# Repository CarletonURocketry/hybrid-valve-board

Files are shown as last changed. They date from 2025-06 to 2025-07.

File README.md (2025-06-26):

# Hybrid Valve Board

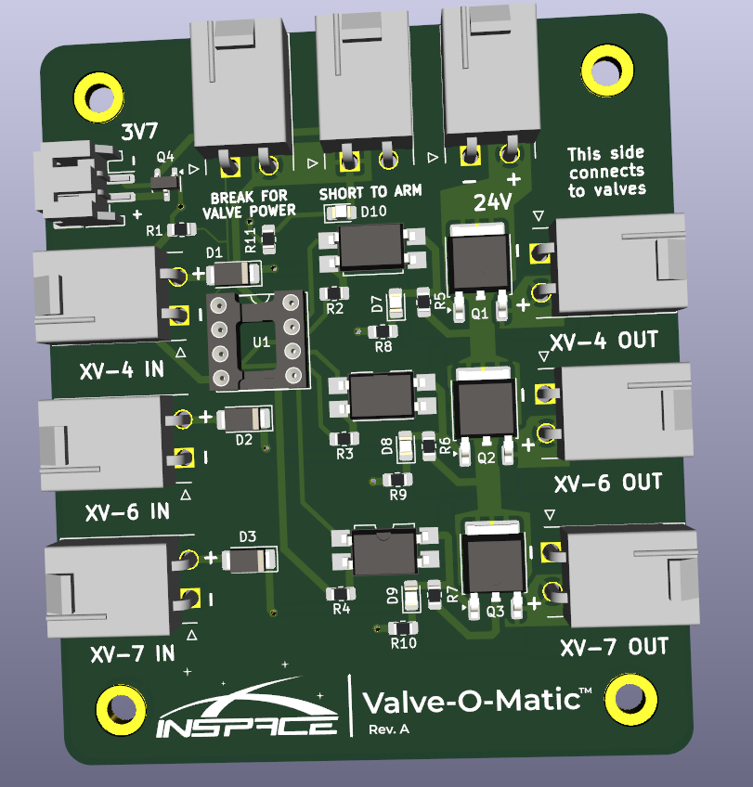
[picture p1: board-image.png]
Board Image


This board keeps the 3 flight valves powered in flight when disconnected from the ground systems in order
to not dump nitrous oxidizer anywhere except the combustion chamber. Otherwise, we don't fly very long.

The board is mainly controlled by an ATTiny85 MCU, and is powered using a Li-Ion battery as well as a 24V (between
20-24V) rail for supplying the solenoids. It is essentially a fancy switch.

You can view the PCB using KiCanvas [here](https://kicanvas.org/?github=https%3A%2F%2Fgithub.com%2FCarletonURocketry%2Fhybrid-valve-board).

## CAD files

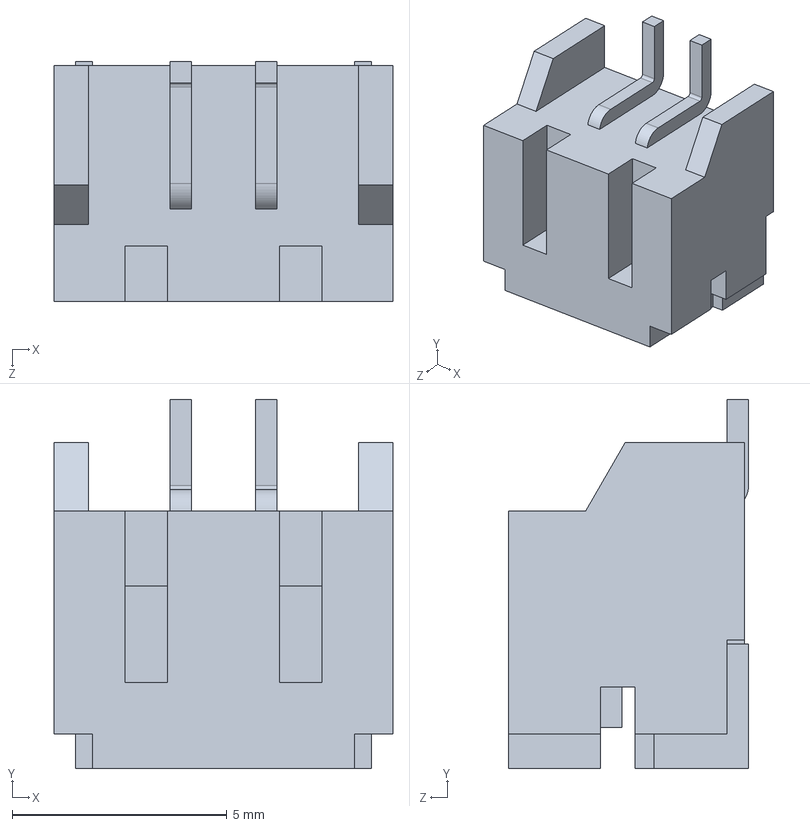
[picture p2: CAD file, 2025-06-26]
LIB_S2B-PH-SM4-TB_LF__SN_/3D/S2B-PH-SM4-TB_LF__SN_.stp
7.90 x 8.60 x 5.60 mm

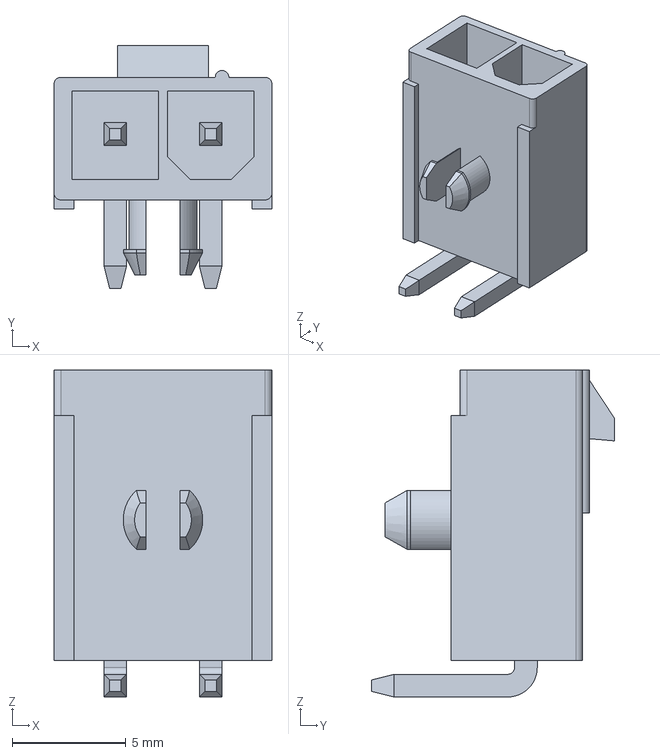
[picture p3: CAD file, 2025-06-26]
LIB_172648-0102/3D/172648-0102.stp
9.60 x 10.7 x 14.4 mm

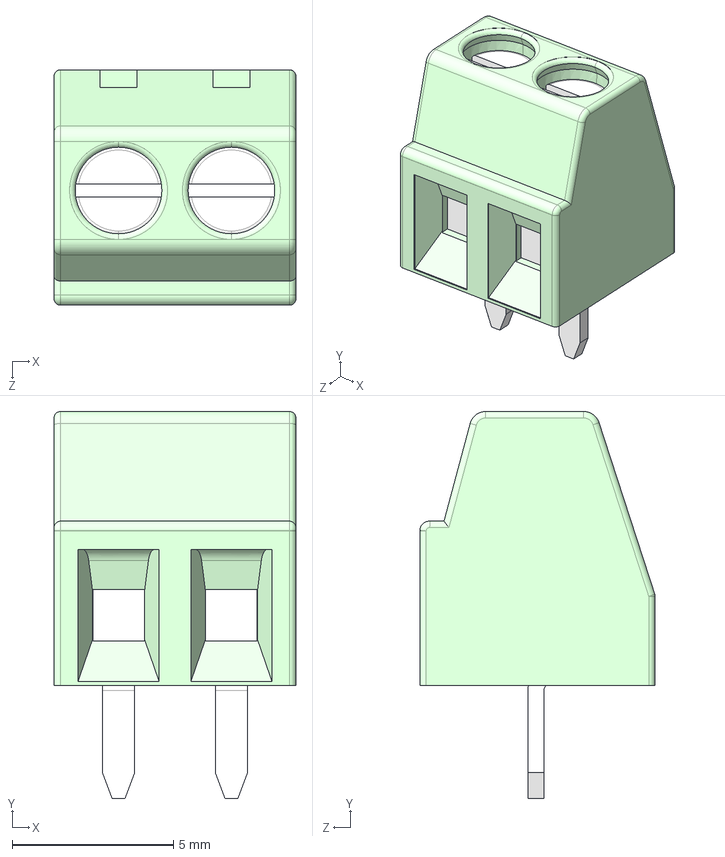
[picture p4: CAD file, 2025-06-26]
LIB_1751248/3D/1751248.stp
7.50 x 12.0 x 7.30 mm

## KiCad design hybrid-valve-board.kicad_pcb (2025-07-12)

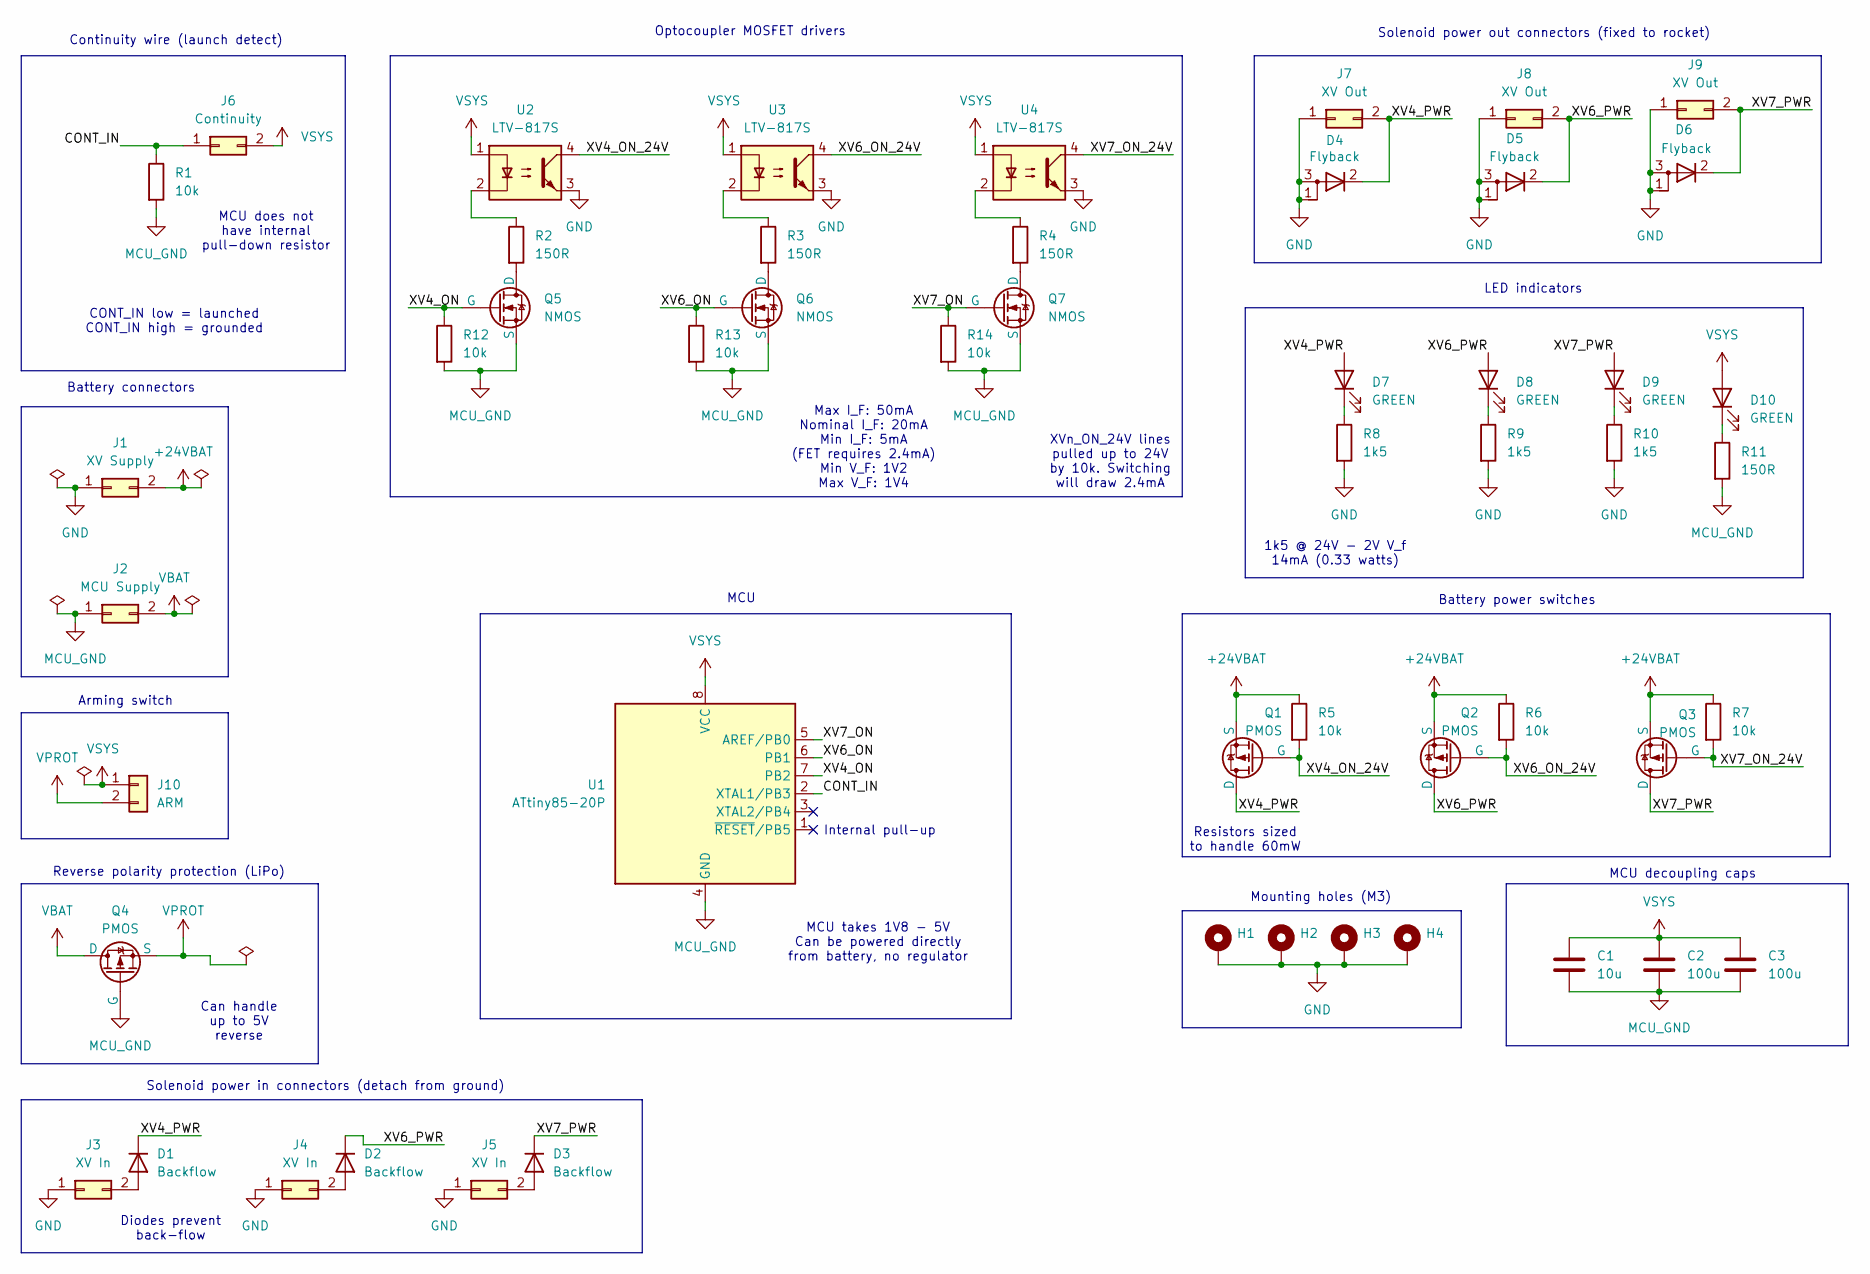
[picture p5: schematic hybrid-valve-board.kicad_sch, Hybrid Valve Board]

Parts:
C1: 10u; C_0805_2012Metric; MPN EMK212BB7106KG-T
C2, C3: 100u; C_0805_2012Metric; MPN CL21A107MQYNNWE
D1, D2, D3: Backflow; D_SOD-128; MPN RBR3LAM60BTR
D4, D5, D6: Flyback; TO-263-2; MPN RFN10NS4STL
D7, D8, D9, D10: GREEN; LED_0805_2012Metric_Pad1.15x1.40mm_HandSolder; MPN HSMG-C170
H1, H2, H3, H4: MountingHole_3.2mm_M3_DIN965_Pad
J1: XV Supply; 1726480102; MPN 172648-0102
J2: MCU Supply; JST_PH_S2B-PH-SM4-TB_1x02-1MP_P2.00mm_Horizontal; MPN 172648-0102
J3, J4, J5: XV In; 1726480102; MPN 172648-0102
J6: Continuity; 1726480102; MPN 172648-0102
J7, J8, J9: XV Out; 1726480102; MPN 172648-0102
J10: ARM; 1726480102; MPN 172648-0102
Q1, Q2, Q3: PMOS; TO-252-2; MPN FQD5P20TM
Q4: PMOS; SOT-23-3; MPN SI2329DS-T1-GE3
Q5, Q6, Q7: NMOS; SOT-23-3; MPN BSH105,215
R1, R5, R6, R7, R12, R13, R14: 10k; R_0805_2012Metric_Pad1.20x1.40mm_HandSolder; MPN CRCW080510K0FKEA
R2, R3, R4, R11: 150R; R_0805_2012Metric_Pad1.20x1.40mm_HandSolder; MPN RK73B2ATTDD151J
R8, R9, R10: 1k5; R_0805_2012Metric_Pad1.20x1.40mm_HandSolder; MPN SDR10EZPJ152
U1: ATtiny85-20P; DIP-8_W7.62mm_Socket; MPN ATTINY85-20PU
U2, U3, U4: LTV-817S; SMDIP-4_W9.53mm; MPN LTV-817S

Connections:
+24VBAT: J1.2, Q1.3 (S), Q2.3 (S), Q3.3 (S), R5.1, R6.1, R7.1
/CONT_IN: J6.1, R1.1, U1.2 (XTAL1/PB3)
/XV4_ON: Q5.1 (G), R12.1, U1.7 (PB2)
/XV4_ON_24V: Q1.1 (G), R5.2, U2.4
/XV4_PWR: D1.1 (K), D4.2 (K), D7.2 (A), J7.2, Q1.2 (D)
/XV6_ON: Q6.1 (G), R13.1, U1.6 (PB1)
/XV6_ON_24V: Q2.1 (G), R6.2, U3.4
/XV6_PWR: D2.1 (K), D5.2 (K), D8.2 (A), J8.2, Q2.2 (D)
/XV7_ON: Q7.1 (G), R14.1, U1.5 (AREF/PB0)
/XV7_ON_24V: Q3.1 (G), R7.2, U4.4
/XV7_PWR: D3.1 (K), D6.2 (K), D9.2 (A), J9.2, Q3.2 (D)
GND: D4.1 (A), D4.3 (A), D5.1 (A), D5.3 (A), D6.1 (A), D6.3 (A), H1.1, H2.1, H3.1, H4.1, J1.1, J3.1, J4.1, J5.1, J7.1, J8.1, J9.1, R8.2, R9.2, R10.2, U2.3, U3.3, U4.3
MCU_GND: C1.2, C2.2, C3.2, J2.1, Q4.1 (G), Q5.2 (S), Q6.2 (S), Q7.2 (S), R1.2, R11.2, R12.2, R13.2, R14.2, U1.4 (GND)
unnamed: D1.2 (A), J3.2
unnamed: D2.2 (A), J4.2
unnamed: D3.2 (A), J5.2
unnamed: D7.1 (K), R8.1
unnamed: D8.1 (K), R9.1
unnamed: D9.1 (K), R10.1
unnamed: D10.1 (K), R11.1
unnamed: Q5.3 (D), R2.2
unnamed: Q6.3 (D), R3.2
unnamed: Q7.3 (D), R4.2
unnamed: R2.1, U2.2
unnamed: R3.1, U3.2
unnamed: R4.1, U4.2
VBAT: J2.2, Q4.3 (D)
VPROT: J10.2, Q4.2 (S)
VSYS: C1.1, C2.1, C3.1, D10.2 (A), J6.2, J10.1, U1.8 (VCC), U2.1, U3.1, U4.1

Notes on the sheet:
Mounting holes (M3)
XVn_ON_24V lines pulled up to 24V by 10k. Switching will draw 2.4mA
MCU decoupling caps
Arming switch
Resistors sized to handle 60mW
Diodes prevent back-flow
Reverse polarity protection (LiPo)
Continuity wire (launch detect)
Battery connectors
Optocoupler MOSFET drivers
MCU
Solenoid power in connectors (detach from ground)
MCU takes 1V8 - 5V Can be powered directly from battery, no regulator
Can handle up to 5V reverse
Max I_F: 50mA Nominal I_F: 20mA Min I_F: 5mA (FET requires 2.4mA) Min V_F: 1V2 Max V_F: 1V4
Solenoid power out connectors (fixed to rocket)
MCU does not have internal pull-down resistor
LED indicators
Battery power switches
1k5 @ 24V - 2V V_f 14mA (0.33 watts)
CONT_IN low = launched CONT_IN high = grounded
Internal pull-up

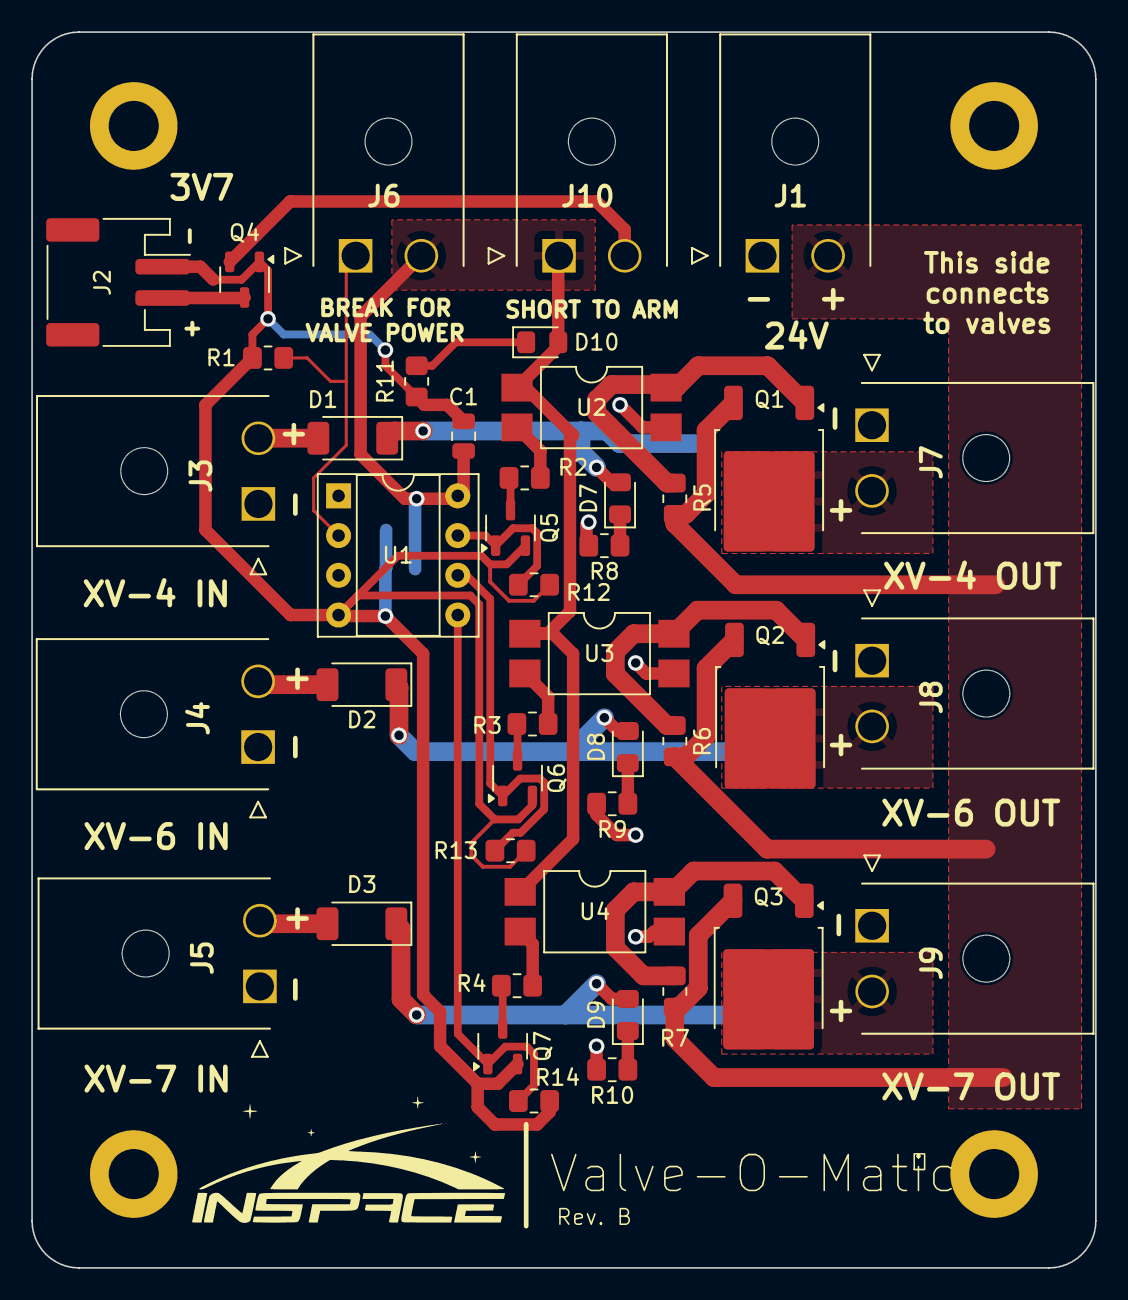
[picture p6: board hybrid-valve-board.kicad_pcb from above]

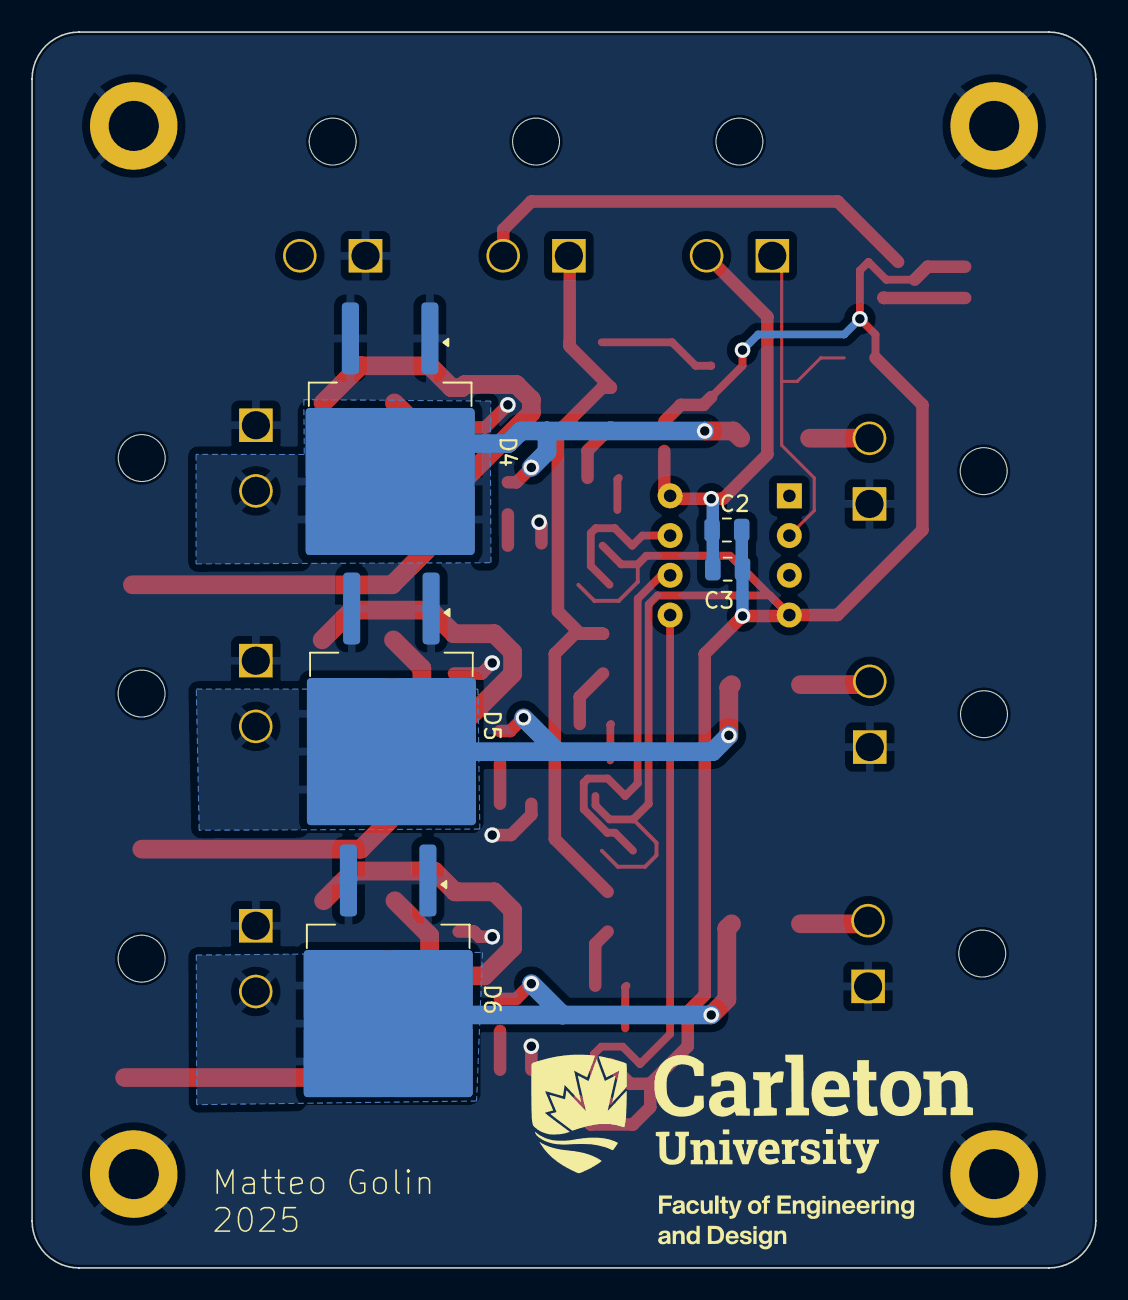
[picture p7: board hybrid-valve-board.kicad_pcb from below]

Board: 2 copper layers, 68.0 x 79.0 mm, 52 parts (5 on the bottom side), 29 nets.

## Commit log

2025-06-26 Initial commit.
    [172648-0102.stp, 1751248.stp, S2B-PH-SM4-TB_LF__SN_.stp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]
2025-06-26 Warranty text
    [hybrid-valve-board.kicad_pcb]
2025-06-26 Picture of board
2025-06-26 Saved schematic change
2025-06-28 Added: reverse polarity protection for MCU, arming LED and PMOS switching
    [hybrid-valve-board.kicad_pcb, hybrid-valve-board.kicad_sch]
2025-06-28 Update BOM
    [hybrid-valve-board.kicad_sch]
2025-06-28 Slightly better copper pours
    [hybrid-valve-board.kicad_pcb]
2025-06-28 Better pour
    [hybrid-valve-board.kicad_pcb]
2025-06-28 Move arming LED closer to arming switch
    [hybrid-valve-board.kicad_pcb]
2025-07-01 Update backflow diodes to identical package that can handle 1.5A at 75C
    [hybrid-valve-board.kicad_sch]
2025-07-01 Added power decoupling capacitors for MCU
    [hybrid-valve-board.kicad_pcb, hybrid-valve-board.kicad_sch]
2025-07-01 Thickened valve power traces from ground systems
    [hybrid-valve-board.kicad_pcb]
2025-07-11 Revision B, with correct connections for the PMOS switches :/
    [hybrid-valve-board.kicad_pcb, hybrid-valve-board.kicad_sch]
2025-07-11 Move LED indicators to power line to avoid interfering with gate signal
    [hybrid-valve-board.kicad_pcb, hybrid-valve-board.kicad_sch]
2025-07-12 Use NMOS to flip opto-coupler
    [hybrid-valve-board.kicad_pcb, hybrid-valve-board.kicad_sch]
2025-07-12 Add pull-down resistor on NMOS gate
    [hybrid-valve-board.kicad_pcb, hybrid-valve-board.kicad_sch]
